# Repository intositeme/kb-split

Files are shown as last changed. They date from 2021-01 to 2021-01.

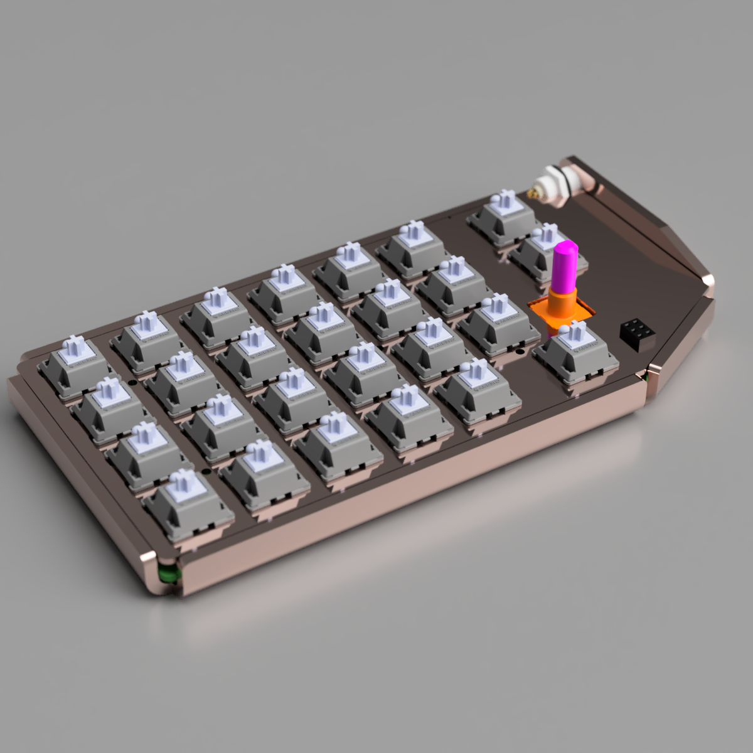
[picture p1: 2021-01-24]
render.PNG

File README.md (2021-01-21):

# kb-split

Big thanks to guys on #QMK discord #hardward channel.

Very first PCB ever designed and produced. 6 cols x 4 rows + 2 extra switch & rotary Encoder
Split olkb keyboard runninf QMK Firmware

Initially designed to use Fischer EGG 0B(board side) with FGG 0B cables, though very expensive ( connectors alone are $40usd+). Added TRS footprint.

Board is reversible, though MCU sits only on 1 side.

- ATmega32u4-AU
- all leds Sk6812
- RGB Underglow & per key RGB
- 1x E11 rotary encoder

* Space bar fits up to 2u but no stabilizers

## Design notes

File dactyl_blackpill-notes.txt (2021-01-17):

 dactyl_blackpill 
    
    MATRIX_COL_PINS { A15, B4, B5, B10, B0, A7 }
    MATRIX_ROW_PINS { B12, B13, B15, A8, A10  }
    MATRIX_COL_PINS_RIGHT { B10, B15, A10, A15, B3, B4 }
    MATRIX_ROW_PINS_RIGHT { B0, A5, A4, A3 }
    
    PINS to avoid: C13, C15, B7, A0, A1 (something to do with PAL mode)
                   B9, B6, 
                   B1, (RGB)
                   B9, (Connect to GND on the slave side)
                   B6, (Serial pin - connect to vcc with a resistor [2.2k to 10k], 
                        Connect to slave half through trrs)

    Blackpill                     

B12 - row0    5v  - N/A              t - gnd 
B13 - row1    GND - GND              r - serial (B6)
B14 -         3.3 - VCC              r - rgb (B1)
B15 - row2    B10 - col3             s - vcc 
A8  - row3    B2  - N/A          
A9  - N/A     B1  - RGB    
A10 - row4    B0  - col4      
A11 - N/A     A7  - col5   
A12 - N/A     A6  -      
A15 - col0    A5  -     
B3  -         A4  -        
B4  - col1    A3  - rot encoder         
B5  - col2    A2  - rot encoder
B6  - serial  A1  -
B7  -         A0  -
B8  -         R   - N/A 
B9  - split   C15 - N/A 
5v  - N/A     C14 - N/A 
GND - GND     C13 - N/A 
3.3 - VCC     VB  - N/A

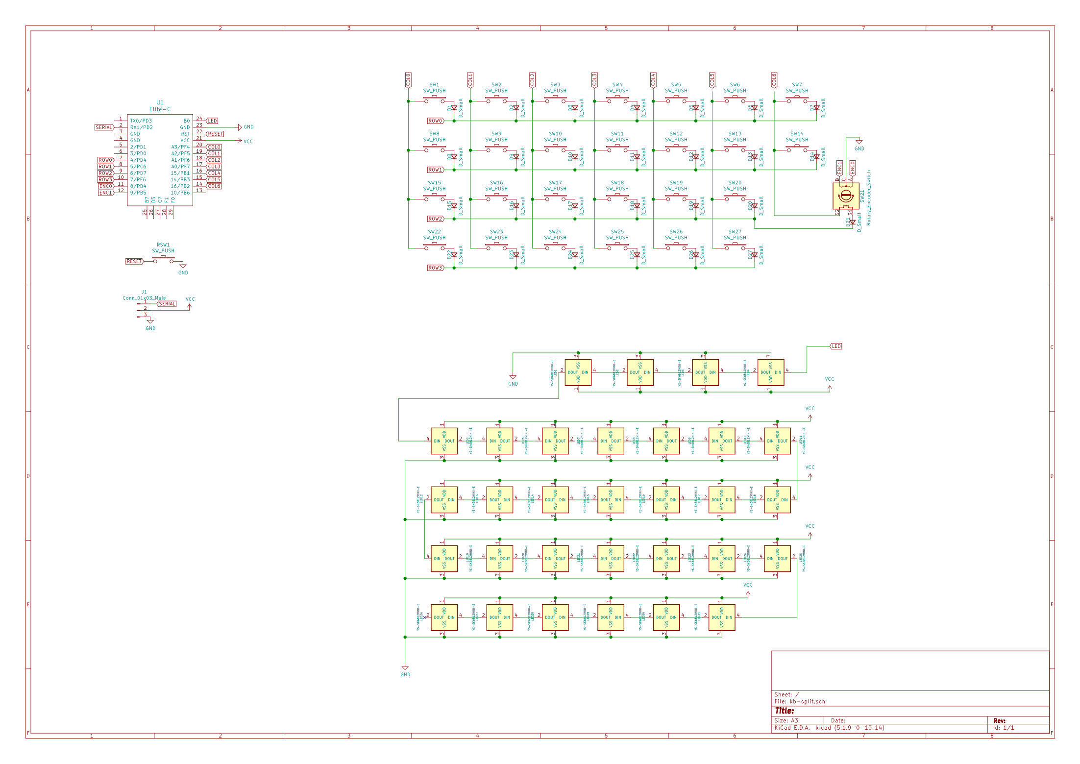
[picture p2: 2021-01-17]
schematic.png

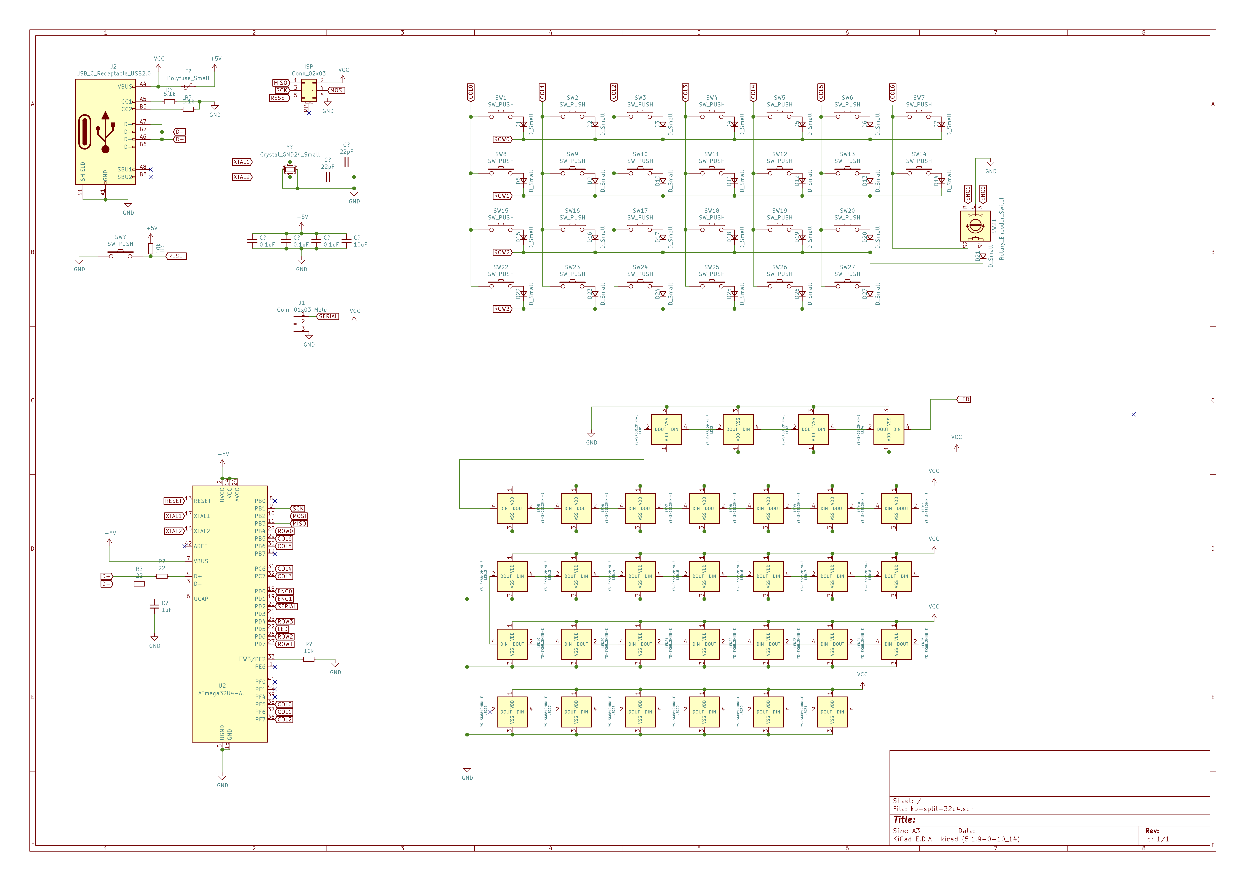
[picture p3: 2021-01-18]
kb-split-32u4.png

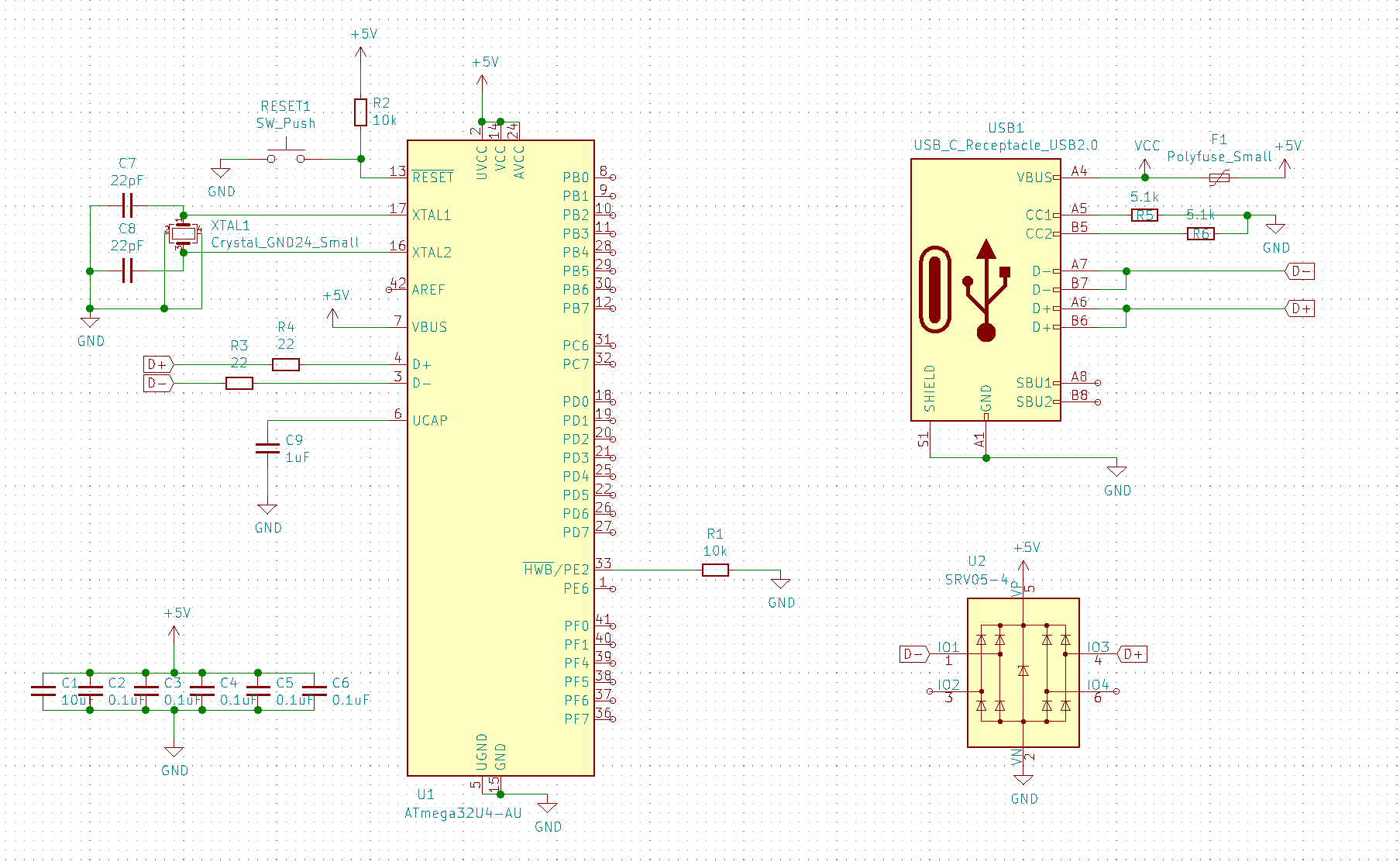
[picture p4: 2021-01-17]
kicad_2021-01-17_17-58-08.png

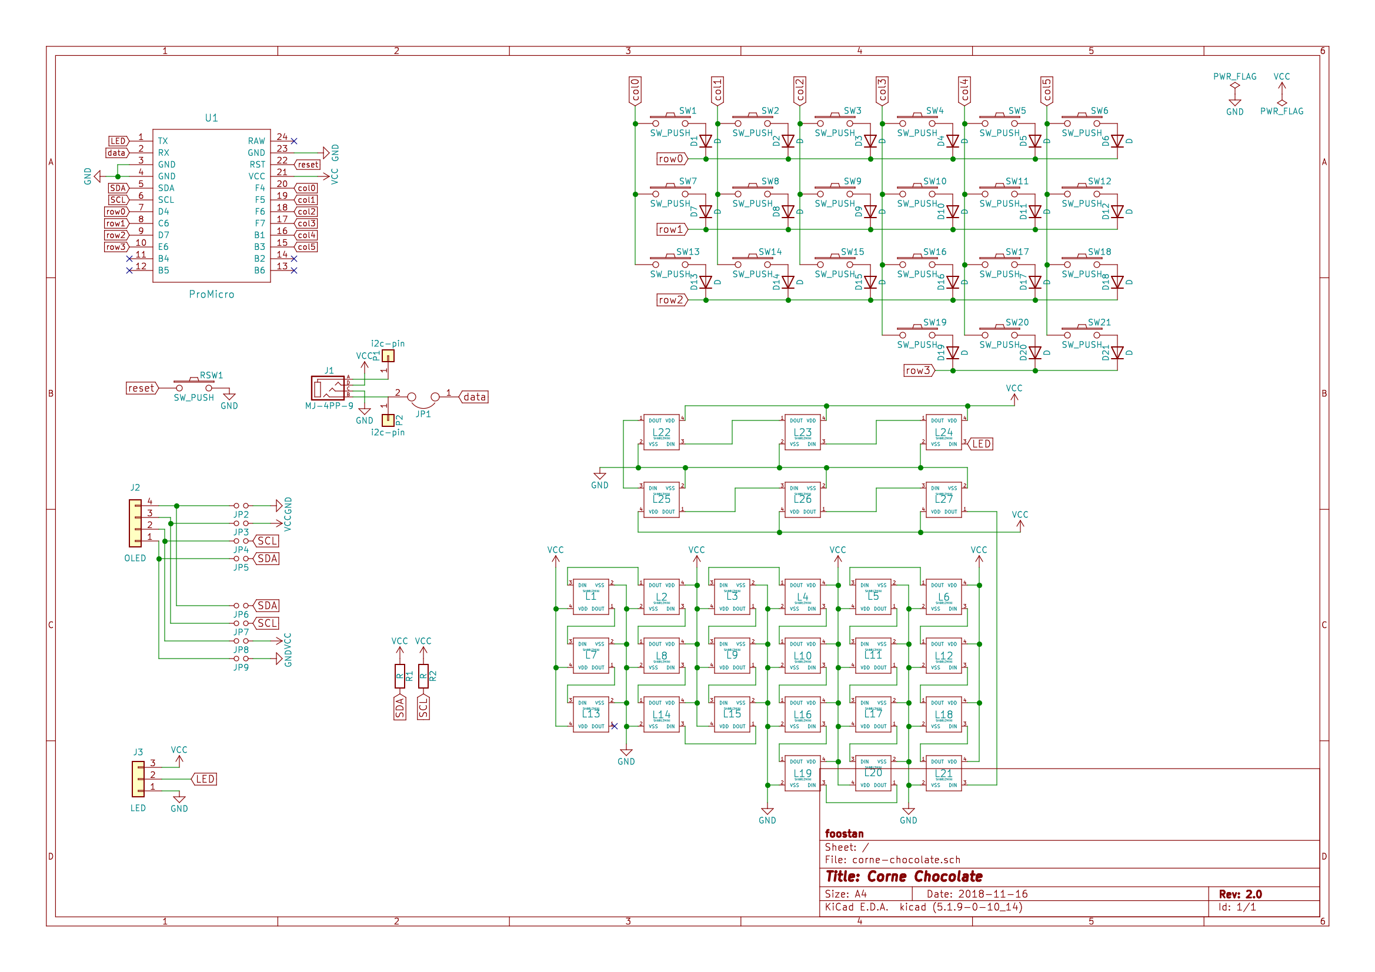
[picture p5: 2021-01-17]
corne layout.png

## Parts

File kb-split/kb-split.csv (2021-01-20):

Reference | Quantity | Value | Footprint | Datasheet
C1 C2 | 2 | 22pF | reversible-kicad-footprints:C-0805_2012Metric | ~
C15 | 1 | 1uF | reversible-kicad-footprints:C-0805_2012Metric | ~
C3 C4 C5 C7 C8 C9 C10 C11 C12 C13 C14 C16 C17 C18 C19 | 15 | 0.1uF | reversible-kicad-footprints:C-0805_2012Metric | ~
C6 | 1 | 10uF | reversible-kicad-footprints:C-0805_2012Metric | ~
D1 D2 D3 D4 D5 D6 D7 D8 D9 D10 D11 D12 D13 D14 D15 D16 D17 D18 D19 D20 D21 D22 D23 D24 D25 D26 D27 | 27 | D_Small | reversible-kicad-footprints:D_SOD-123 | ~
F1 | 1 | Polyfuse_Small | reversible-kicad-footprints:Fuse_1206_3216Metric | ~
H1 H2 H3 H4 H5 | 5 | MountingHole | kbd:M2_HOLE_v3 | ~
ISP1 | 1 | Conn_02x03 | Connector_PinSocket_2.54mm:PinSocket_2x03_P2.54mm_Vertical | ~
J1 | 1 | USB_C_Receptacle_USB2.0 | reversible-kicad-footprints:HRO-TYPE-C-31-M-12-HandSoldering-NoSBU | https://www.usb.org/sites/default/files/documents/usb_type-c.zip
J2 | 1 | Conn_01x03_Male | Connector_PinSocket_2.54mm:PinSocket_1x03_P2.54mm_Horizontal | ~
LED1 LED2 LED3 LED4 LED25 | 5 | YS-SK6812MINI-E | reversible-kicad-footprints:SK6812Mini-E
LED5 LED6 LED7 LED8 LED9 LED10 LED11 LED12 LED13 LED14 LED15 LED16 LED17 LED18 LED19 LED20 LED21 LED22 LED23 LED24 LED26 LED27 LED28 LED29 LED30 LED31 | 26 | YS-SK6812MINI-E | reversible-kicad-footprints:MX-1U-SK6812Mini-E
R1 R2 | 2 | 5.1k | reversible-kicad-footprints:R-0805_2012Metric | ~
R4 R5 | 2 | 22 | reversible-kicad-footprints:R-0805_2012Metric | ~
R3 R6 | 2 | 10k | reversible-kicad-footprints:R-0805_2012Metric | ~
SW15 | 1 | Rotary_Encoder_Switch | reversible-kicad-footprints:MX-1U-EC11_Switch | ~
SW1 SW2 SW3 SW4 SW5 SW6 SW7 SW8 SW9 SW10 SW11 SW12 SW13 SW14 SW16 SW17 SW18 SW19 SW20 SW21 SW23 SW24 SW25 SW26 SW27 SW28 | 26 | SW_PUSH | reversible-kicad-footprints:MX-1U-Hotswap
SW22 | 1 | SW_PUSH | reversible-kicad-footprints:SMD_Push
U1 | 1 | SRV05-4 | reversible-kicad-footprints:SOT-23-6 | http://www.onsemi.com/pub/Collateral/SRV05-4-D.PDF
U2 | 1 | ATmega32U4-AU | Package_QFP:TQFP-44_10x10mm_P0.8mm | http://ww1.microchip.com/downloads/en/DeviceDoc/Atmel-7766-8-bit-AVR-ATmega16U4-32U4_Datasheet.pdf
Y1 | 1 | Crystal_GND24_Small | intositeme:Reversible-Crystal_SMD_3225-4pin_3.2x2.5mm | ~

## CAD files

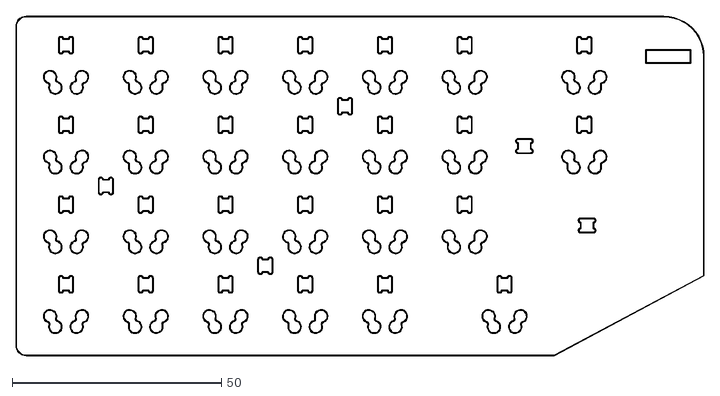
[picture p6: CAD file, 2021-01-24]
kb-split/export/kb-split-Edge_Cuts.dxf
164.4 x 81.0

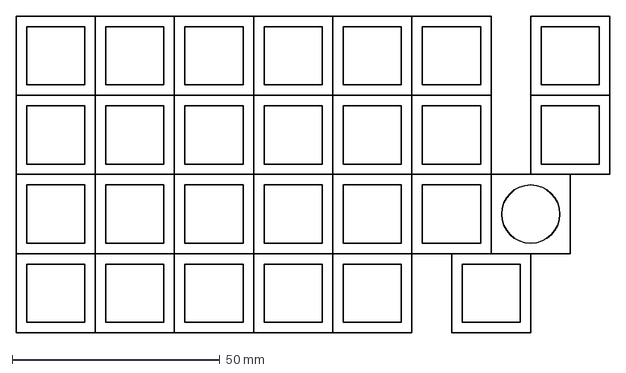
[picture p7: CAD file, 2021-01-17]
layout2.dxf
142.9 x 76.2 mm

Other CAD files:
layout.dxf
kb-split/export/kb-split-B_Mask.dxf
kb-split/export/kb-split-F_Mask.dxf

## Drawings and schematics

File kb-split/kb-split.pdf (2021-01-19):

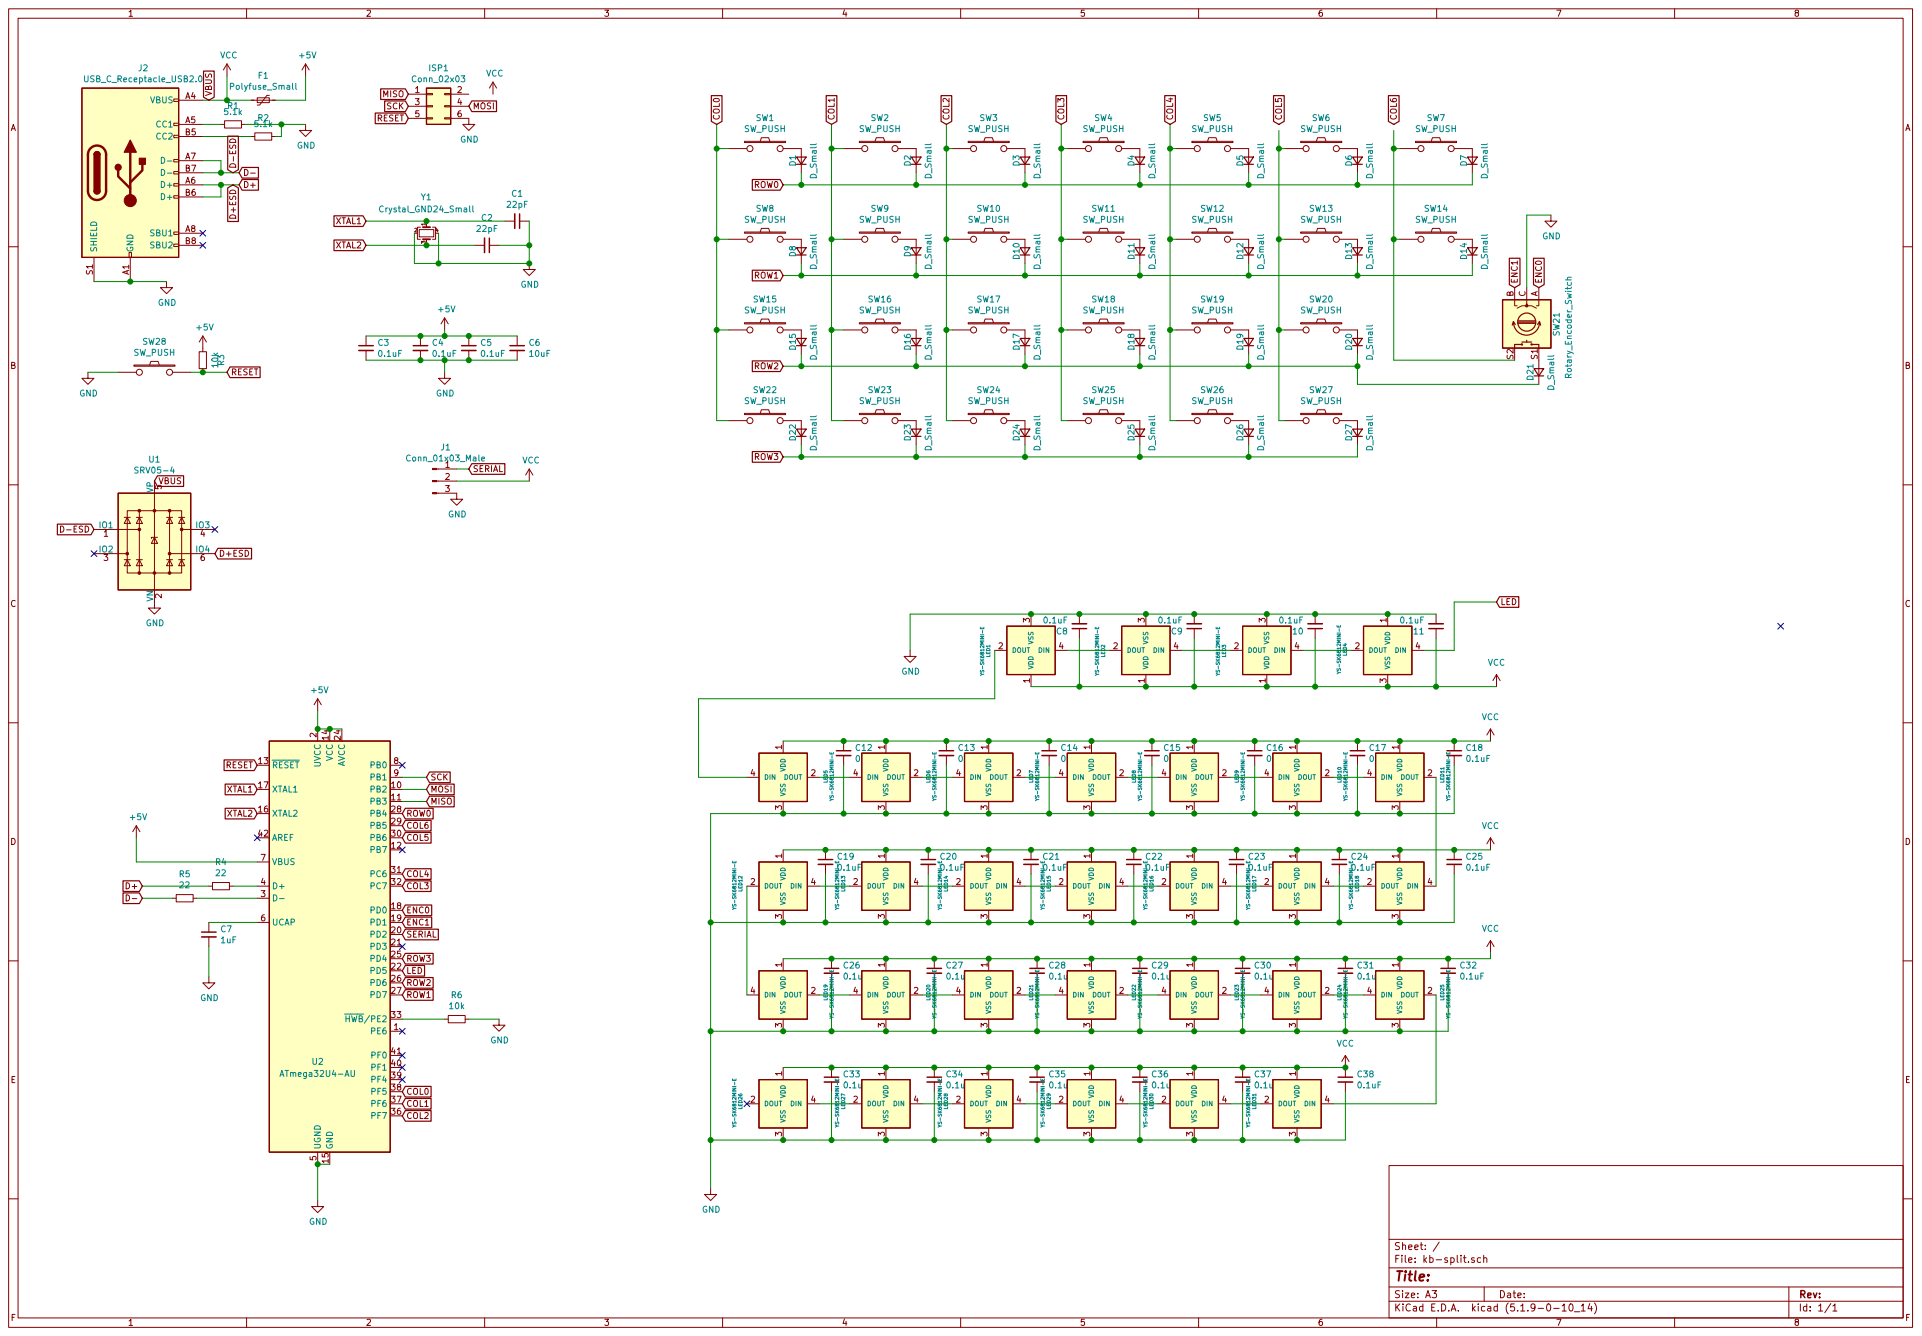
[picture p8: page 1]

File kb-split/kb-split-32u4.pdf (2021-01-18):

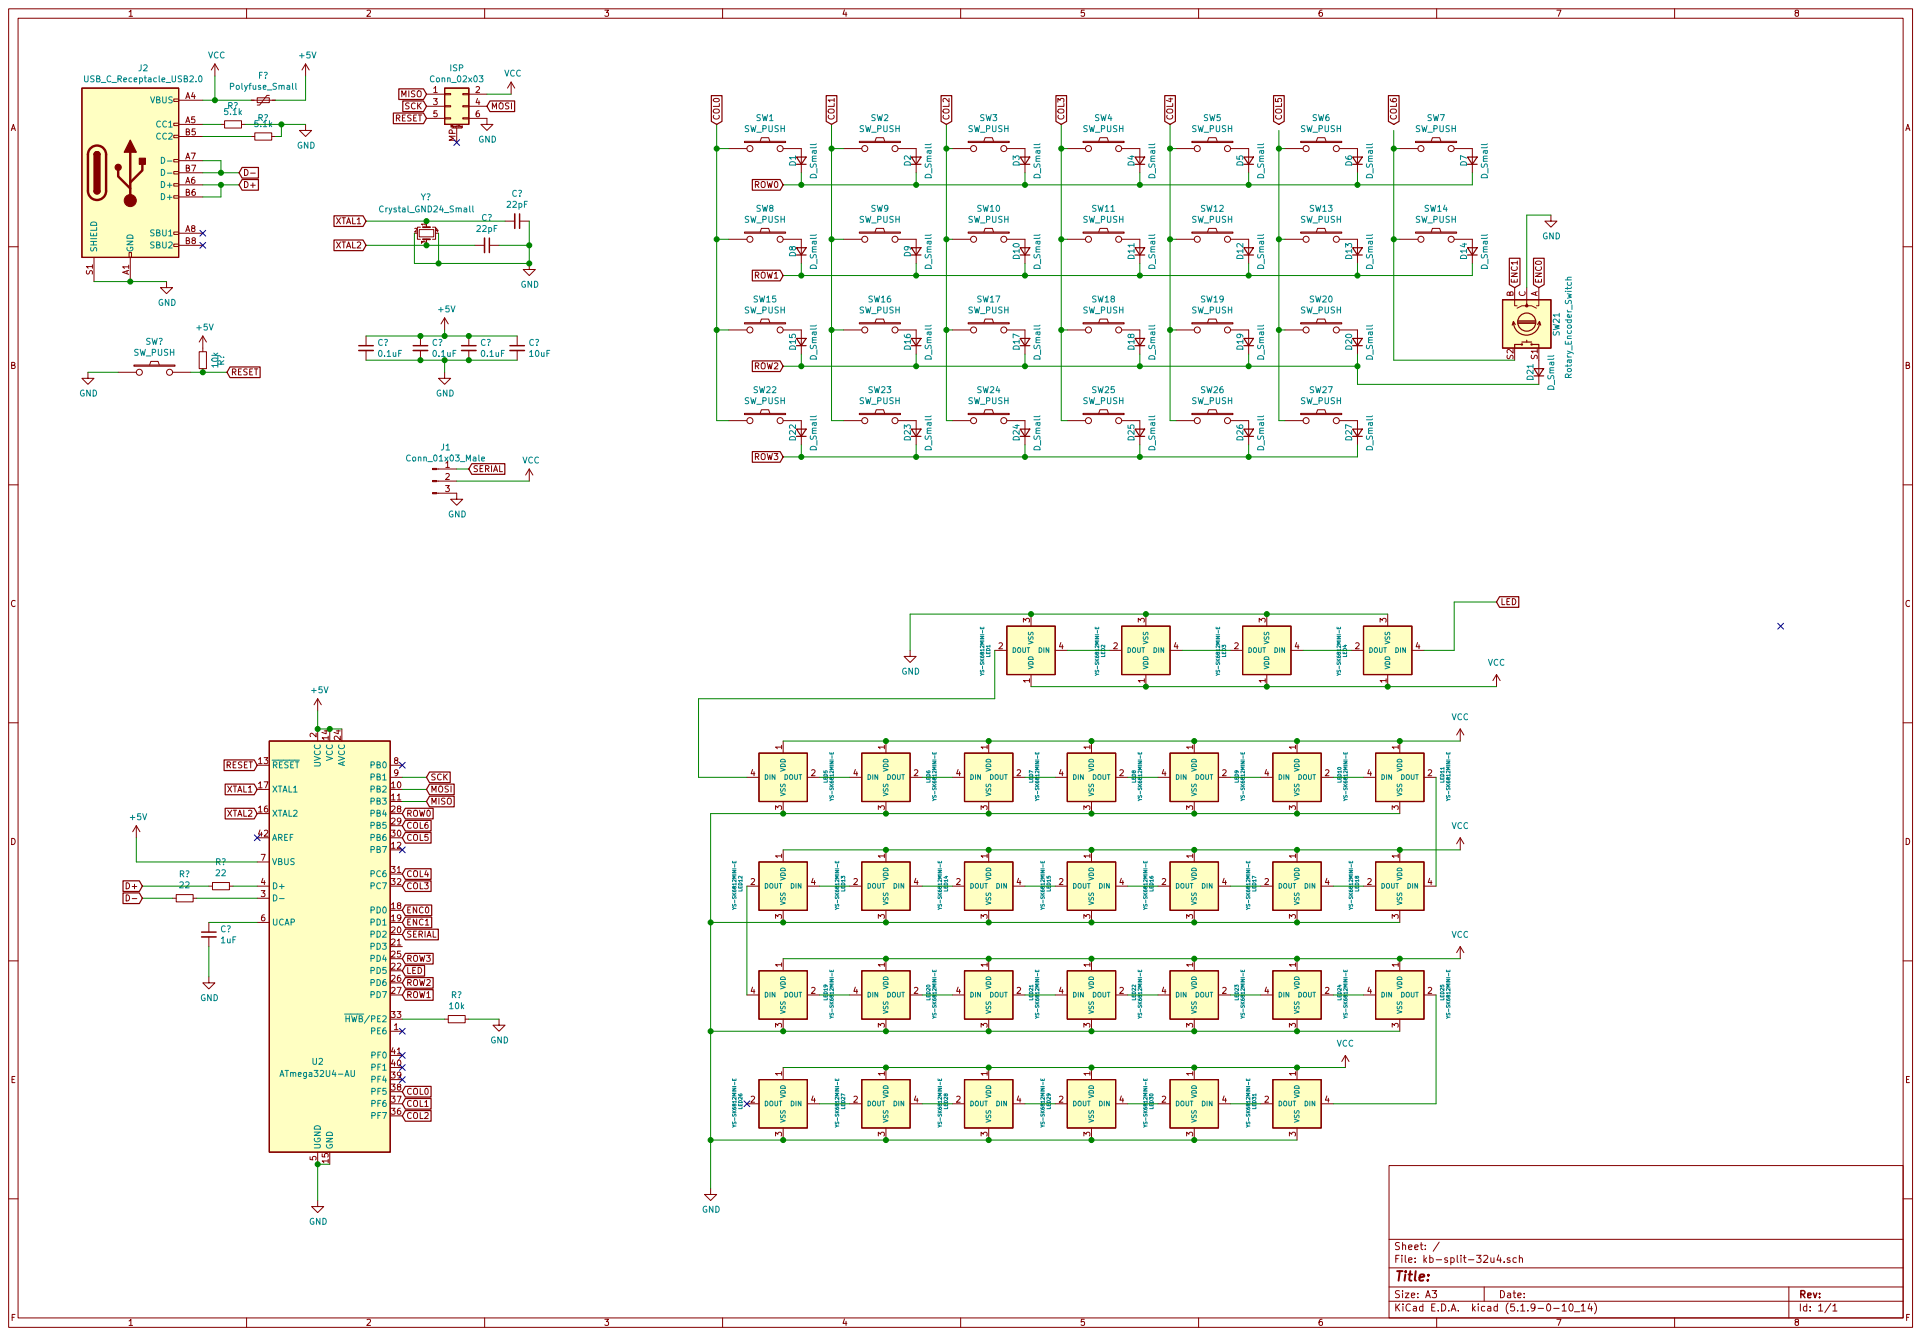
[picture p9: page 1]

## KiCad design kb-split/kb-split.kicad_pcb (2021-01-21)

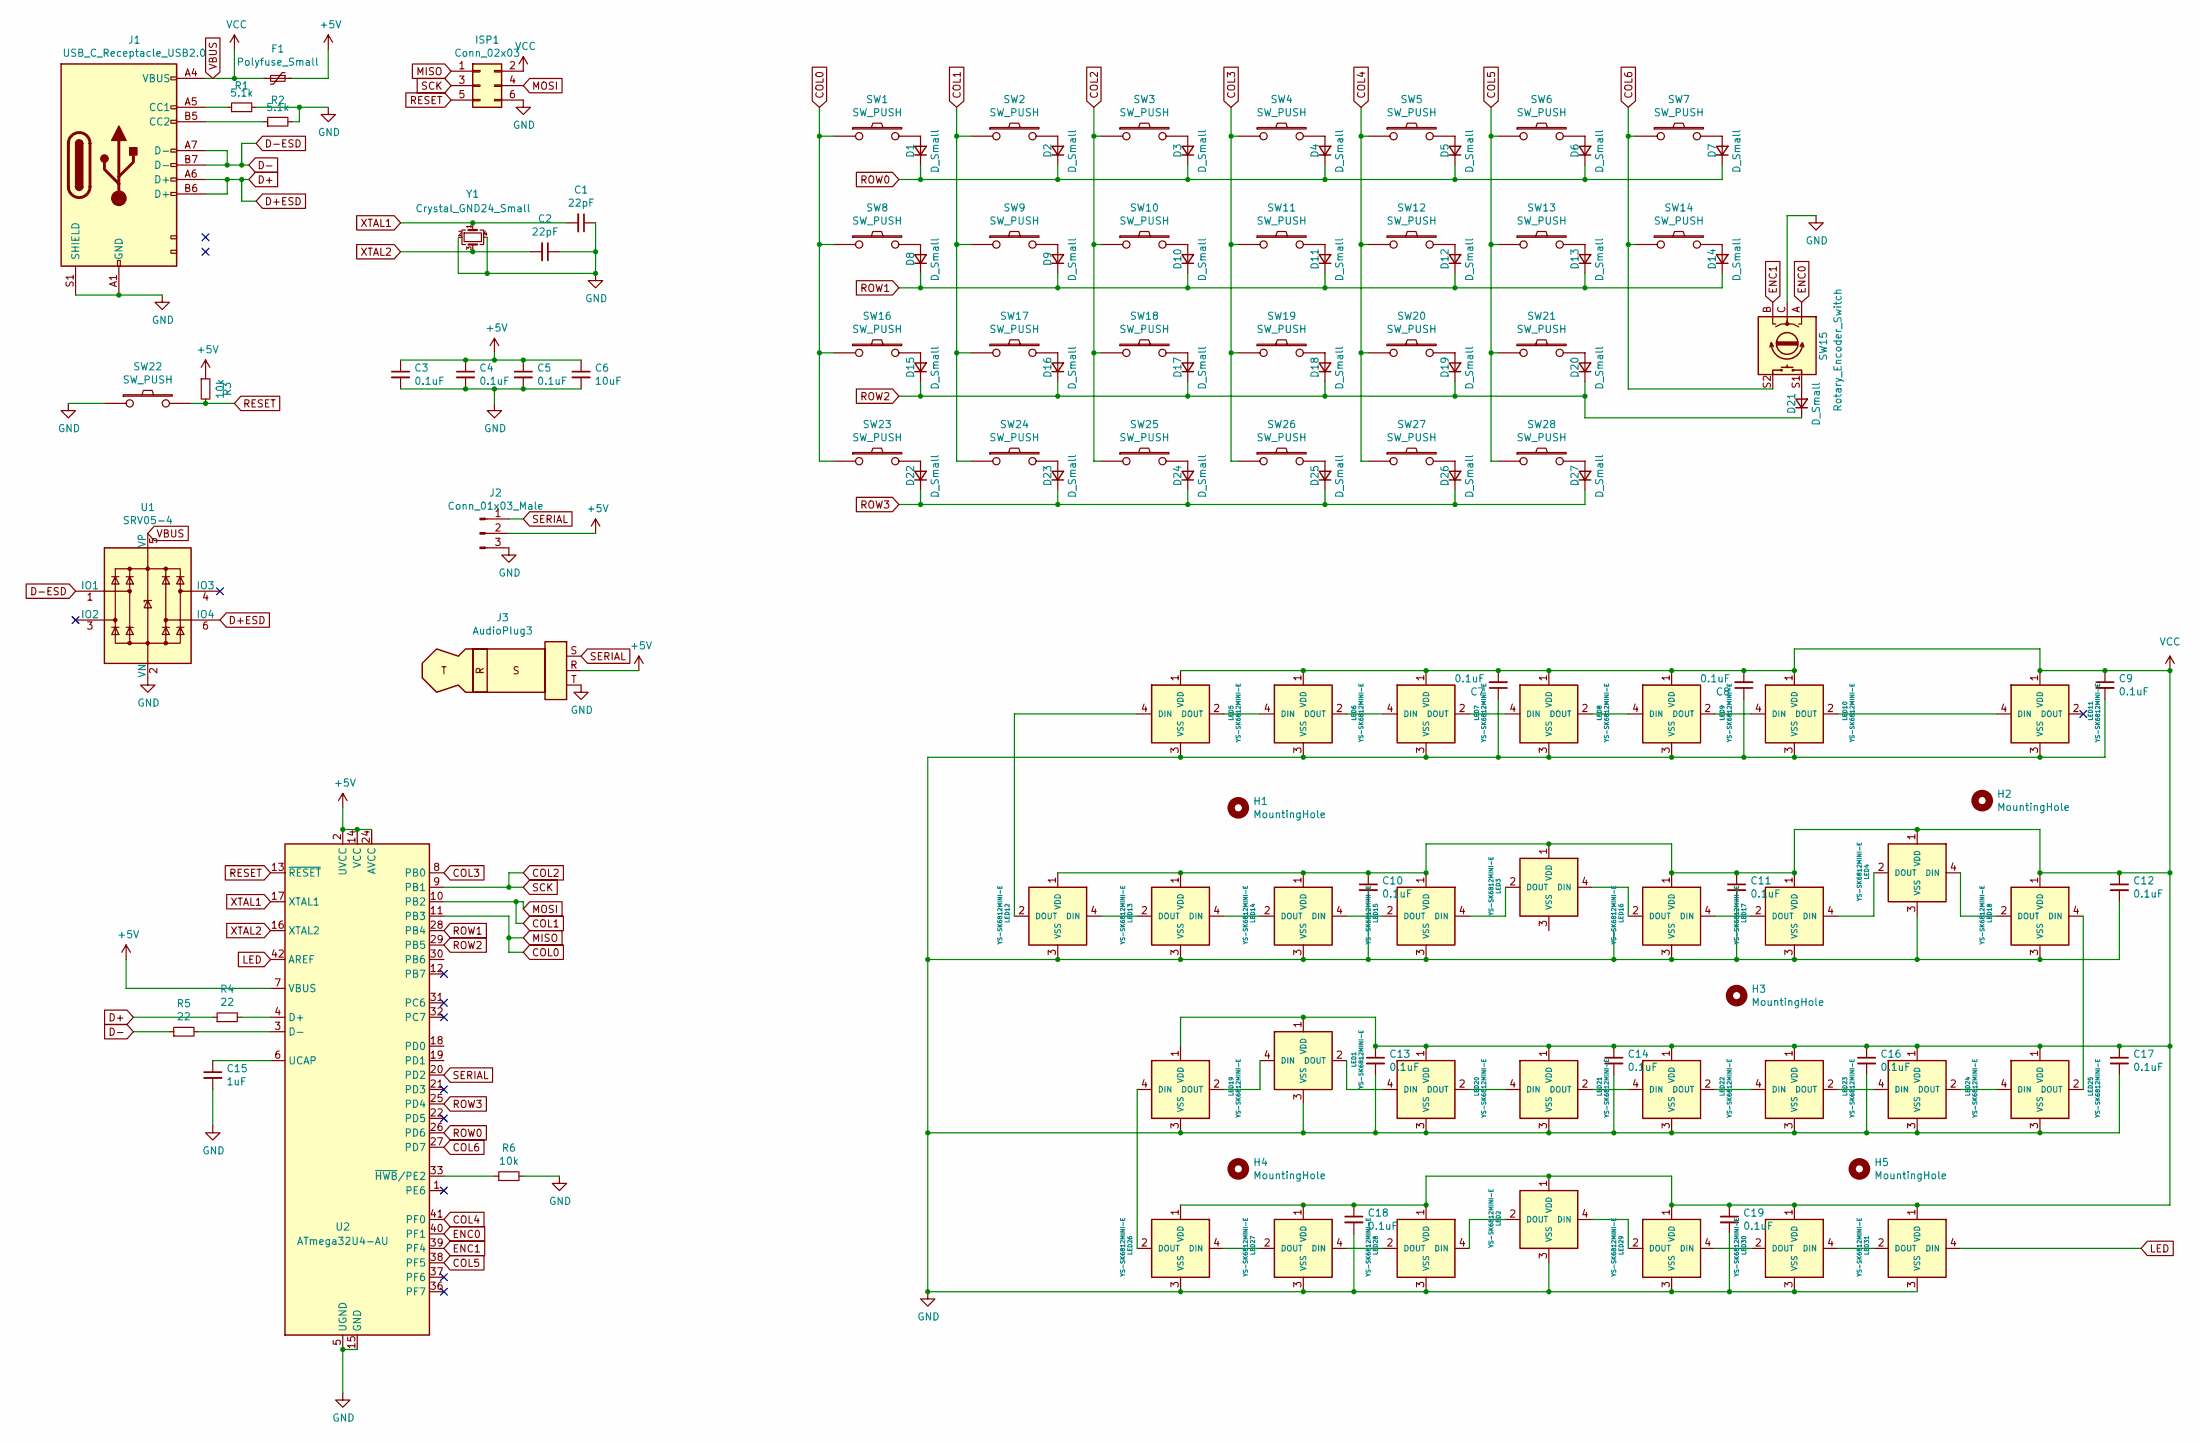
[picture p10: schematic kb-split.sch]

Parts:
C1, C2: 22pF; C-0805_2012Metric
C3, C4, C5, C7, C8, C9, C10, C11, C12, C13, C14, C16, C17, C18, C19: 0.1uF; C-0805_2012Metric
C6: 10uF; C-0805_2012Metric
C15: 1uF; C-0805_2012Metric
D1, D2, D3, D4, D5, D6, D7, D8, D9, D10, D11, D12, D13, D14, D15, D16, D17, D18, D19, D20, D21, D22, D23, D24, D25, D26, D27: D_Small; D_SOD-123
F1: Polyfuse_Small; Fuse_1206_3216Metric
H1, H2, H3, H4, H5: MountingHole; M2_HOLE_v3
ISP1: Conn_02x03; PinSocket_2x03_P2.54mm_Vertical
J1: USB_C_Receptacle_USB2.0; HRO-TYPE-C-31-M-12-HandSoldering-NoSBU
J2: Conn_01x03_Male; PinSocket_1x03_P2.54mm_Horizontal
J3: AudioPlug3; PJ-3136-B
LED1, LED2, LED3, LED4, LED25: YS-SK6812MINI-E; SK6812Mini-E
LED5, LED6, LED7, LED8, LED9, LED10, LED11, LED12, LED13, LED14, LED15, LED16, LED17, LED18, LED19, LED20, LED21, LED22, LED23, LED24, LED26, LED27, LED28, LED29, LED30, LED31: YS-SK6812MINI-E; MX-1U-SK6812Mini-E
R1, R2: 5.1k; R-0805_2012Metric
R3, R6: 10k; R-0805_2012Metric
R4, R5: 22; R-0805_2012Metric
SW1, SW2, SW3, SW4, SW5, SW6, SW7, SW8, SW9, SW10, SW11, SW12, SW13, SW14, SW16, SW17, SW18, SW19, SW20, SW21, SW23, SW24, SW25, SW26, SW27, SW28: SW_PUSH; MX-1U-Hotswap
SW15: Rotary_Encoder_Switch; MX-1U-EC11_Switch
SW22: SW_PUSH; SMD_Push
U1: SRV05-4; SOT-23-6
U2: ATmega32U4-AU; TQFP-44_10x10mm_P0.8mm
Y1: Crystal_GND24_Small; Reversible-Crystal_SMD_3225-4pin_3.2x2.5mm

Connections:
+5V: C3.1, C4.1, C5.1, C6.1, F1.1, J2.2, J3.R, R3.1, U2.2 (UVCC), U2.7 (VBUS), U2.14 (VCC), U2.24 (AVCC), U2.34 (VCC), U2.44 (AVCC)
COL0: ISP1.1, SW1.1, SW8.1, SW16.1, SW23.1, U2.11 (PB3)
COL1: ISP1.4, SW2.1, SW9.1, SW17.1, SW24.1, U2.10 (PB2)
COL2: ISP1.3, SW3.1, SW10.1, SW18.1, SW25.1, U2.9 (PB1)
COL3: SW4.1, SW11.1, SW19.1, SW26.1, U2.8 (PB0)
COL4: SW5.1, SW12.1, SW20.1, SW27.1, U2.41 (PF0)
COL5: SW6.1, SW13.1, SW21.1, SW28.1, U2.38 (PF5)
COL6: SW7.1, SW14.1, SW15.S2, U2.27 (PD7)
D+: J1.A6 (D+), J1.B6 (D+), R4.1, U1.6 (IO4)
D-: J1.A7 (D-), J1.B7 (D-), R5.1, U1.1 (IO1)
ENC0: SW15.A, U2.40 (PF1)
ENC1: SW15.B, U2.39 (PF4)
GND: C1.1, C2.1, C3.2, C4.2, C5.2, C6.2, C7.1, C8.1, C9.2, C10.2, C11.2, C12.2, C13.2, C14.2, C15.2, C16.2, C17.2, C18.2, C19.2, ISP1.6, J1.A1 (GND), J1.B1 (GND), J1.S1 (SHIELD), J2.3, J3.T, LED1.3 (VSS), LED2.3 (VSS), LED4.3 (VSS), LED5.3 (VSS), LED6.3 (VSS), LED7.3 (VSS), LED8.3 (VSS), LED9.3 (VSS), LED10.3 (VSS), LED11.3 (VSS), LED12.3 (VSS), LED13.3 (VSS), LED14.3 (VSS), LED15.3 (VSS), LED16.3 (VSS), LED17.3 (VSS), LED18.3 (VSS), LED19.3 (VSS), LED20.3 (VSS), LED21.3 (VSS), LED22.3 (VSS), LED23.3 (VSS), LED24.3 (VSS), LED25.3 (VSS), LED26.3 (VSS), LED27.3 (VSS), LED28.3 (VSS), LED29.3 (VSS), LED30.3 (VSS), LED31.3 (VSS), R1.2, R2.2, R6.2, SW15.C, SW22.1, U1.2 (VN), U2.5 (UGND), U2.15 (GND), U2.23 (GND), U2.35 (GND), U2.43 (GND), Y1.2, Y1.4
LED: LED31.4 (DIN), U2.42 (AREF)
unnamed: C15.1, U2.6 (UCAP)
unnamed: D1.2 (A), SW1.2
unnamed: D2.2 (A), SW2.2
unnamed: D3.2 (A), SW3.2
unnamed: D4.2 (A), SW4.2
unnamed: D5.2 (A), SW5.2
unnamed: D6.2 (A), SW6.2
unnamed: D7.2 (A), SW7.2
unnamed: D8.2 (A), SW8.2
unnamed: D9.2 (A), SW9.2
unnamed: D10.2 (A), SW10.2
unnamed: D11.2 (A), SW11.2
unnamed: D12.2 (A), SW12.2
unnamed: D13.2 (A), SW13.2
unnamed: D14.2 (A), SW14.2
unnamed: D15.2 (A), SW16.2
unnamed: D16.2 (A), SW17.2
unnamed: D17.2 (A), SW18.2
unnamed: D18.2 (A), SW19.2
unnamed: D19.2 (A), SW20.2
unnamed: D20.2 (A), SW21.2
unnamed: D21.2 (A), SW15.S1
unnamed: D22.2 (A), SW23.2
unnamed: D23.2 (A), SW24.2
unnamed: D24.2 (A), SW25.2
unnamed: D25.2 (A), SW26.2
unnamed: D26.2 (A), SW27.2
unnamed: D27.2 (A), SW28.2
unnamed: J1.A5 (CC1), R1.1
unnamed: J1.B5 (CC2), R2.1
unnamed: LED1.2 (DOUT), LED20.4 (DIN)
unnamed: LED1.4 (DIN), LED19.2 (DOUT)
unnamed: LED2.2 (DOUT), LED28.4 (DIN)
unnamed: LED2.4 (DIN), LED29.2 (DOUT)
unnamed: LED5.2 (DOUT), LED6.4 (DIN)
unnamed: LED6.2 (DOUT), LED7.4 (DIN)
unnamed: LED7.2 (DOUT), LED8.4 (DIN)
unnamed: LED8.2 (DOUT), LED9.4 (DIN)
unnamed: LED10.2 (DOUT), LED11.4 (DIN)
unnamed: LED9.2 (DOUT), LED10.4 (DIN)
unnamed: LED5.4 (DIN), LED12.2 (DOUT)
unnamed: LED12.4 (DIN), LED13.2 (DOUT)
unnamed: LED13.4 (DIN), LED14.2 (DOUT)
unnamed: LED14.4 (DIN), LED15.2 (DOUT)
unnamed: LED3.2 (DOUT), LED15.4 (DIN)
unnamed: LED3.4 (DIN), LED16.2 (DOUT)
unnamed: LED16.4 (DIN), LED17.2 (DOUT)
unnamed: LED4.2 (DOUT), LED17.4 (DIN)
unnamed: LED4.4 (DIN), LED18.2 (DOUT)
unnamed: LED18.4 (DIN), LED25.2 (DOUT)
unnamed: LED19.4 (DIN), LED26.2 (DOUT)
unnamed: LED20.2 (DOUT), LED21.4 (DIN)
unnamed: LED21.2 (DOUT), LED22.4 (DIN)
unnamed: LED22.2 (DOUT), LED23.4 (DIN)
unnamed: LED23.2 (DOUT), LED24.4 (DIN)
unnamed: LED24.2 (DOUT), LED25.4 (DIN)
unnamed: LED26.4 (DIN), LED27.2 (DOUT)
unnamed: LED27.4 (DIN), LED28.2 (DOUT)
unnamed: LED29.4 (DIN), LED30.2 (DOUT)
unnamed: LED30.4 (DIN), LED31.2 (DOUT)
unnamed: R4.2, U2.4 (D+)
unnamed: R5.2, U2.3 (D-)
unnamed: R6.1, U2.33 (~HWB~/PE2)
RESET: ISP1.5, R3.2, SW22.2, U2.13 (~RESET)
ROW0: D1.1 (K), D2.1 (K), D3.1 (K), D4.1 (K), D5.1 (K), D6.1 (K), D7.1 (K), U2.26 (PD6)
ROW1: D8.1 (K), D9.1 (K), D10.1 (K), D11.1 (K), D12.1 (K), D13.1 (K), D14.1 (K), U2.28 (PB4)
ROW2: D15.1 (K), D16.1 (K), D17.1 (K), D18.1 (K), D19.1 (K), D20.1 (K), D21.1 (K), U2.29 (PB5)
ROW3: D22.1 (K), D23.1 (K), D24.1 (K), D25.1 (K), D26.1 (K), D27.1 (K), U2.25 (PD4)
SERIAL: J2.1, J3.S, U2.20 (PD2)
VBUS: C7.2, C8.2, C9.1, C10.1, C11.1, C12.1, C13.1, C14.1, C16.1, C17.1, C18.1, C19.1, F1.2, ISP1.2, J1.A4 (VBUS), J1.B4 (VBUS), LED1.1 (VDD), LED2.1 (VDD), LED3.1 (VDD), LED4.1 (VDD), LED5.1 (VDD), LED6.1 (VDD), LED7.1 (VDD), LED8.1 (VDD), LED9.1 (VDD), LED10.1 (VDD), LED11.1 (VDD), LED12.1 (VDD), LED13.1 (VDD), LED14.1 (VDD), LED15.1 (VDD), LED16.1 (VDD), LED17.1 (VDD), LED18.1 (VDD), LED19.1 (VDD), LED20.1 (VDD), LED21.1 (VDD), LED22.1 (VDD), LED23.1 (VDD), LED24.1 (VDD), LED25.1 (VDD), LED26.1 (VDD), LED27.1 (VDD), LED28.1 (VDD), LED29.1 (VDD), LED30.1 (VDD), LED31.1 (VDD), U1.5 (VP)
XTAL1: C1.2, U2.17 (XTAL1), Y1.1
XTAL2: C2.2, U2.16 (XTAL2), Y1.3

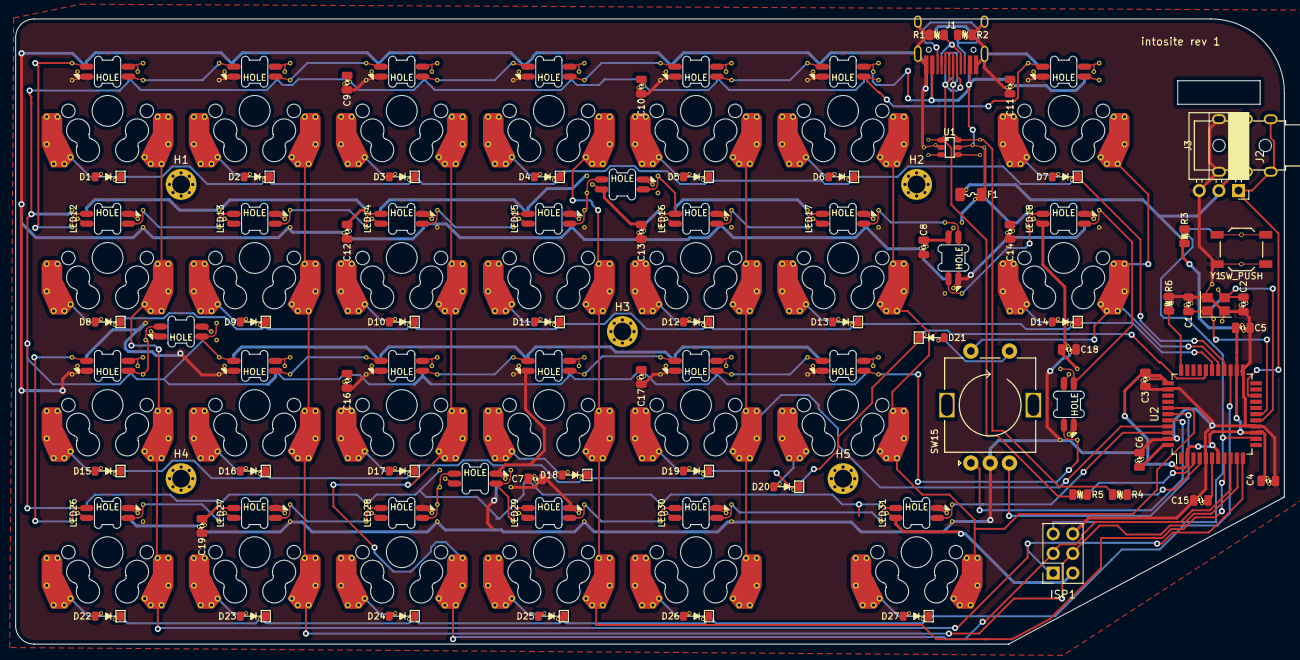
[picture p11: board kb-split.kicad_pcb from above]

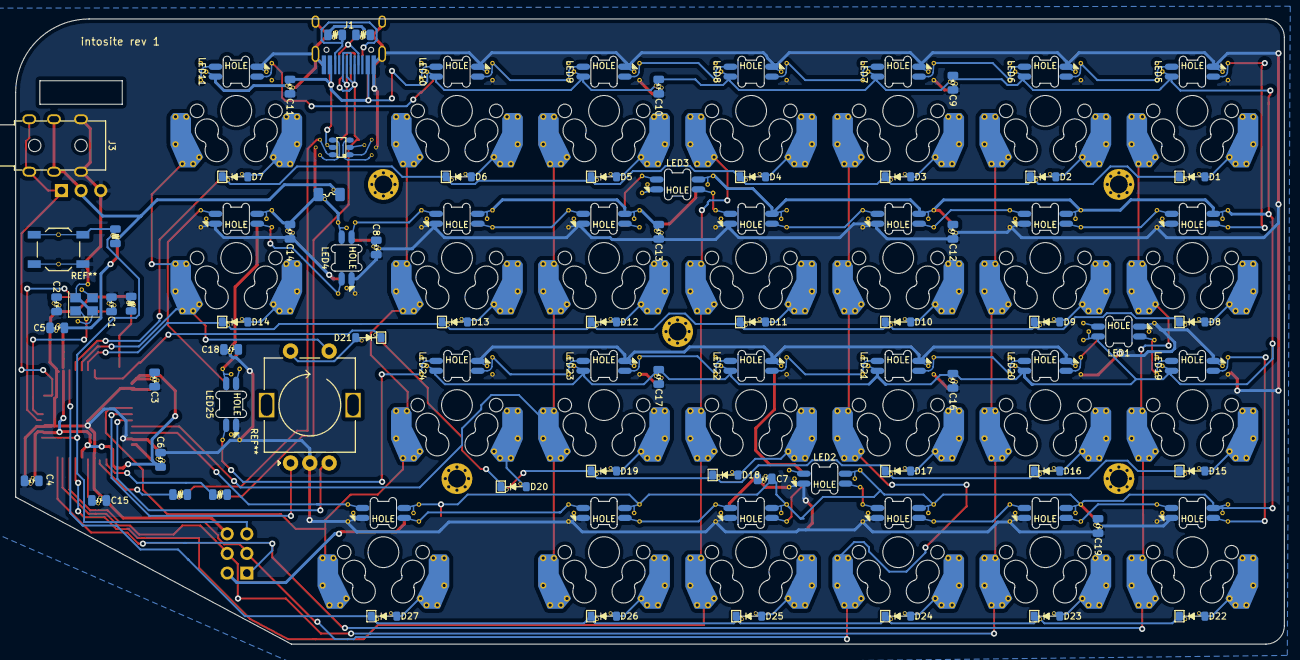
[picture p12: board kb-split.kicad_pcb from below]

Board: 2 copper layers, 164.3 x 81.0 mm, 124 parts (13 on the bottom side), 86 nets.

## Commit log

2021-01-17 Schematic updates
    [kb-split.kicad_pcb, kb-split.sch]
2021-01-17 Added Layout Template
    [kb-split.kicad_pcb, kb-split.sch, layout.dxf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]
2021-01-17 Added USB C schematic
2021-01-18 redo schematic to remove eliteC and use atmega32u4 directly
    [kb-split-elite-c.sch, kb-split.kicad_pcb]
2021-01-19 Create reversible Cystal footprint
    [kb-split.kicad_pcb, kb-split.sch]
2021-01-19 Layout components
    [kb-split.kicad_pcb, kb-split.sch]
2021-01-19 Adding trace
    [kb-split.kicad_pcb]
2021-01-20 Done routing.
    [kb-split.dsn, kb-split.kicad_pcb, kb-split.sch]
2021-01-20 Rev 1. Sent to manufacture. Added ground fills
    [kb-split.kicad_pcb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]
2021-01-20 Created BOM
    [kb-split.csv]
2021-01-21 Added trs and fix gerbers export
    [kb-split-B_Cu.gbr, kb-split-B_Mask.gbr, kb-split-B_SilkS.gbr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]
2021-01-21 Update gerber export. Passed JLC verification
    [kb-split-B_Cu.gbr, kb-split-B_Mask.gbr, kb-split-B_SilkS.gbr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]
2021-01-24 Added render case
    [kb-split-B_Mask.dxf, kb-split-Edge_Cuts.dxf, kb-split-F_Mask.dxf]
